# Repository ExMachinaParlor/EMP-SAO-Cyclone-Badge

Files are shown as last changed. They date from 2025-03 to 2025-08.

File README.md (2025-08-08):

# EMP SAO Cyclone Badge
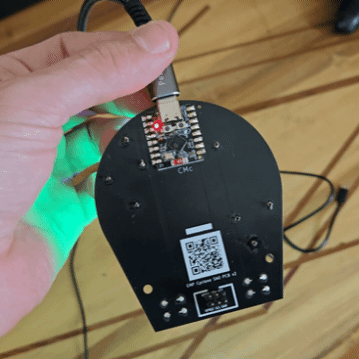
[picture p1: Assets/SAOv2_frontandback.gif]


# Description
SAO with a simple arcade game similar to the classic Cyclone. Made to run on an ESP32-C3 and to interface with [Neopixel rings](https://www.adafruit.com/product/1463#technical-details).

# How to Play
## Attract Mode
A rotating purple LED on the outer ring and a slow blink of green on the inner ring is the default state
The SAO waits for a button press to transition to START_GAME

## Start Game
Resets the chasing light and randomly selects one of the LEDs to act as the target
Displays the jackpot briefly with a blue color. Immediately transitions to PLAY_GAME

## Play Game
A single lit LED moves around the outer ring.
The goal is to press the button when the active LED is over the previously displayed target LED

## Result
If the button is pressed when the active LED is on the target, it’s a win animation of flashing green
Otherwise, a lose animation of flashing red
After the animation the SAO returns to ATTRACT_MODE

# SAO BOM
- 1x [ESP32-C3 Nano](https://www.amazon.com/ESP32-C3-Development-Bluetooth-Running-Frequency/dp/B0DFWG87JS/?th=1)
- 1x [24 LED Neopixel ring](https://www.amazon.com/dp/B0B2D7742J)
- 1x [16 LED Neopixel ring](https://www.amazon.com/dp/B0B2D5QXG5)
- 2x [Push buttons](https://www.amazon.com/dp/B01CGMP9GY)
- 1x [2x3 0.1" Header pin box connector](https://www.amazon.com/gp/product/B00UBWKQLA/)
- 1x [SAO PCB](./PCB/EMP_Cyclone_SAO_v2/Gerber.zip)
- 8x 0.1" Header pins (Included in ESP32-C3 purchase)

# Flashing the Badge
- Use the arduino IDE
- Set board type to "nologo ESP32C3 Supermini"

# Future Work
- Add multiplayer mode
- Test with WLED and home assistant
- Use WiFi/BT to synchonize lights on multiple badges

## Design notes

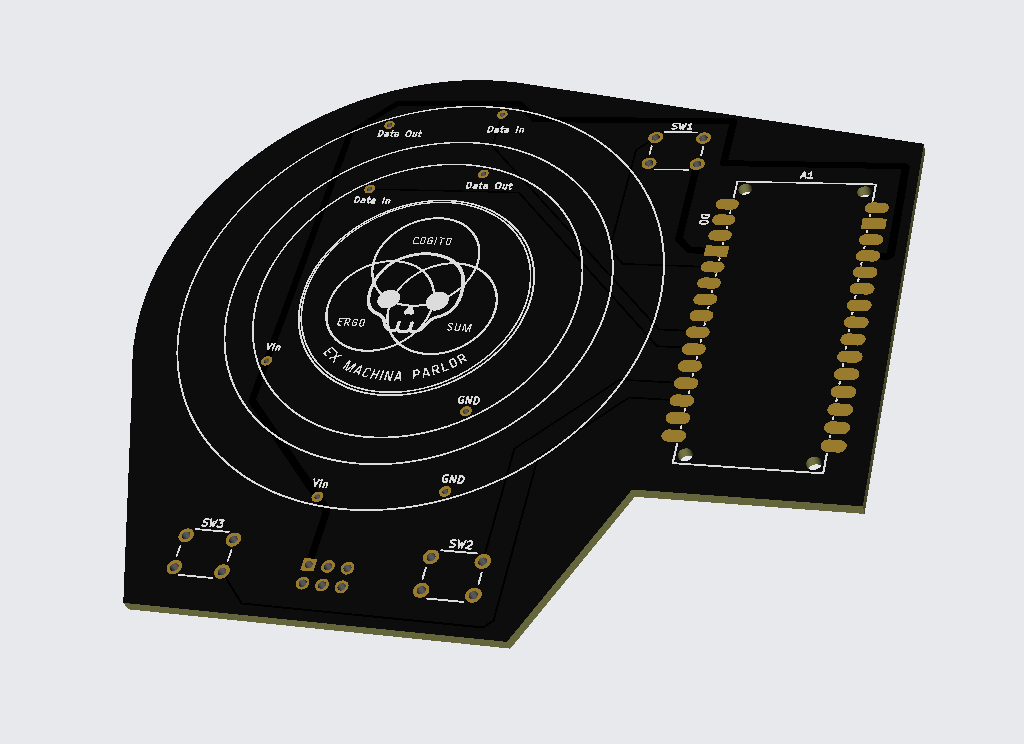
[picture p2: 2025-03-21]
Assets/PCBv1.png

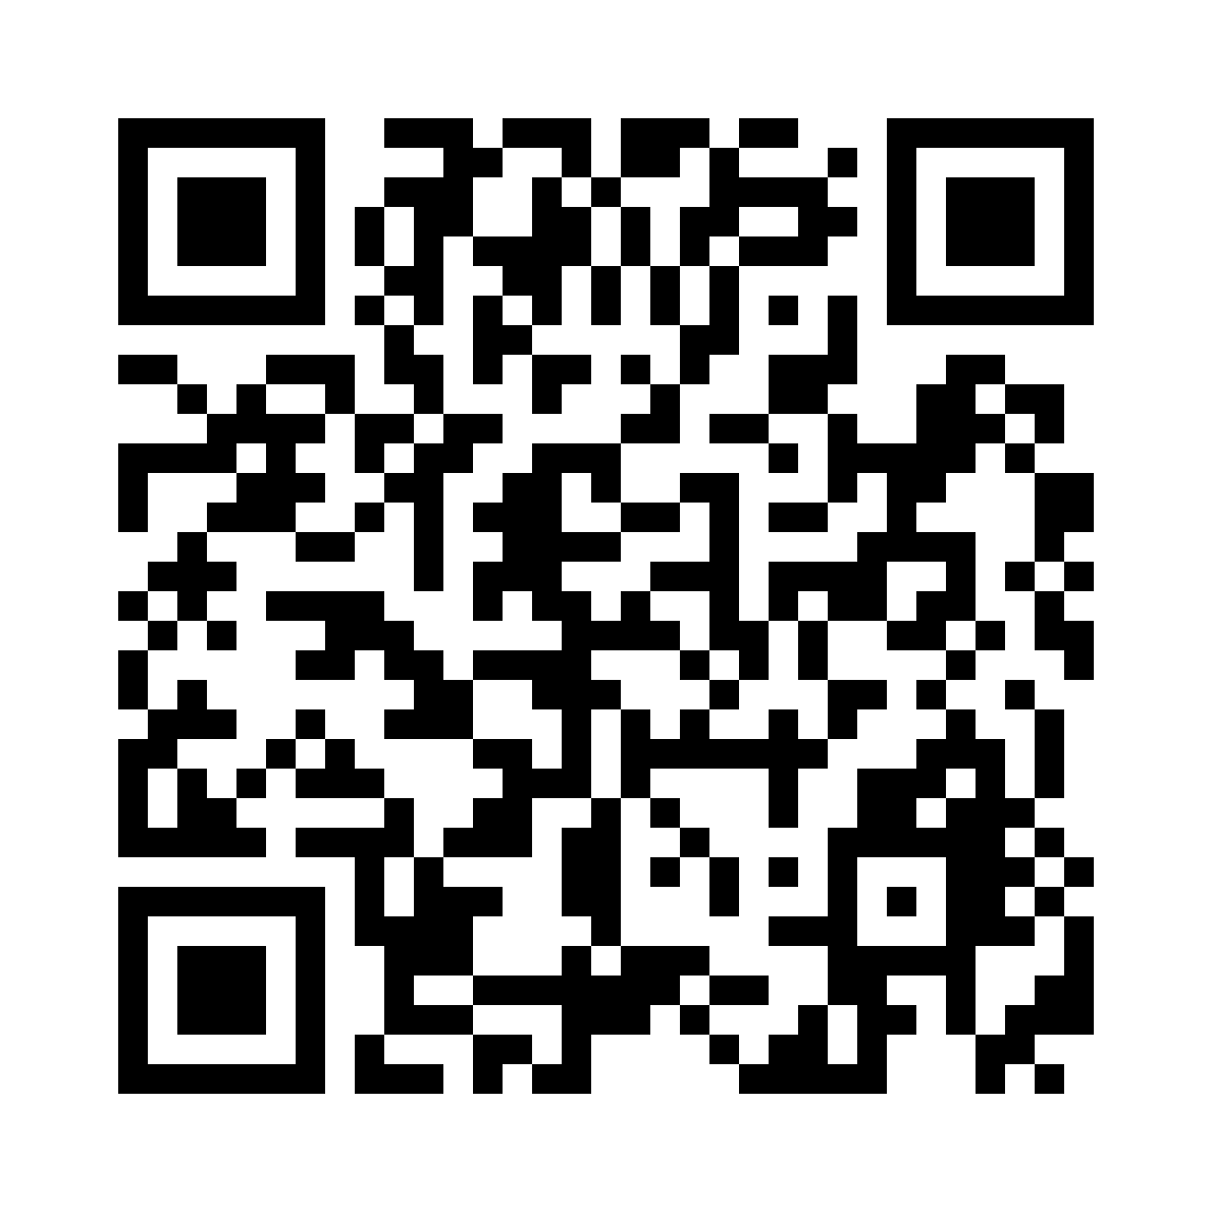
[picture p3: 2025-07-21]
Assets/repoQR.png

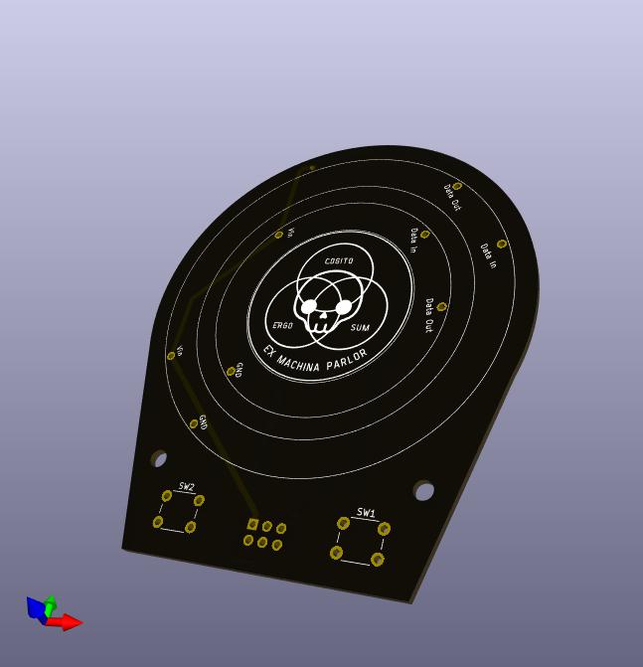
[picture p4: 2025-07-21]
Assets/SAOv2_3Dpcb.jpg

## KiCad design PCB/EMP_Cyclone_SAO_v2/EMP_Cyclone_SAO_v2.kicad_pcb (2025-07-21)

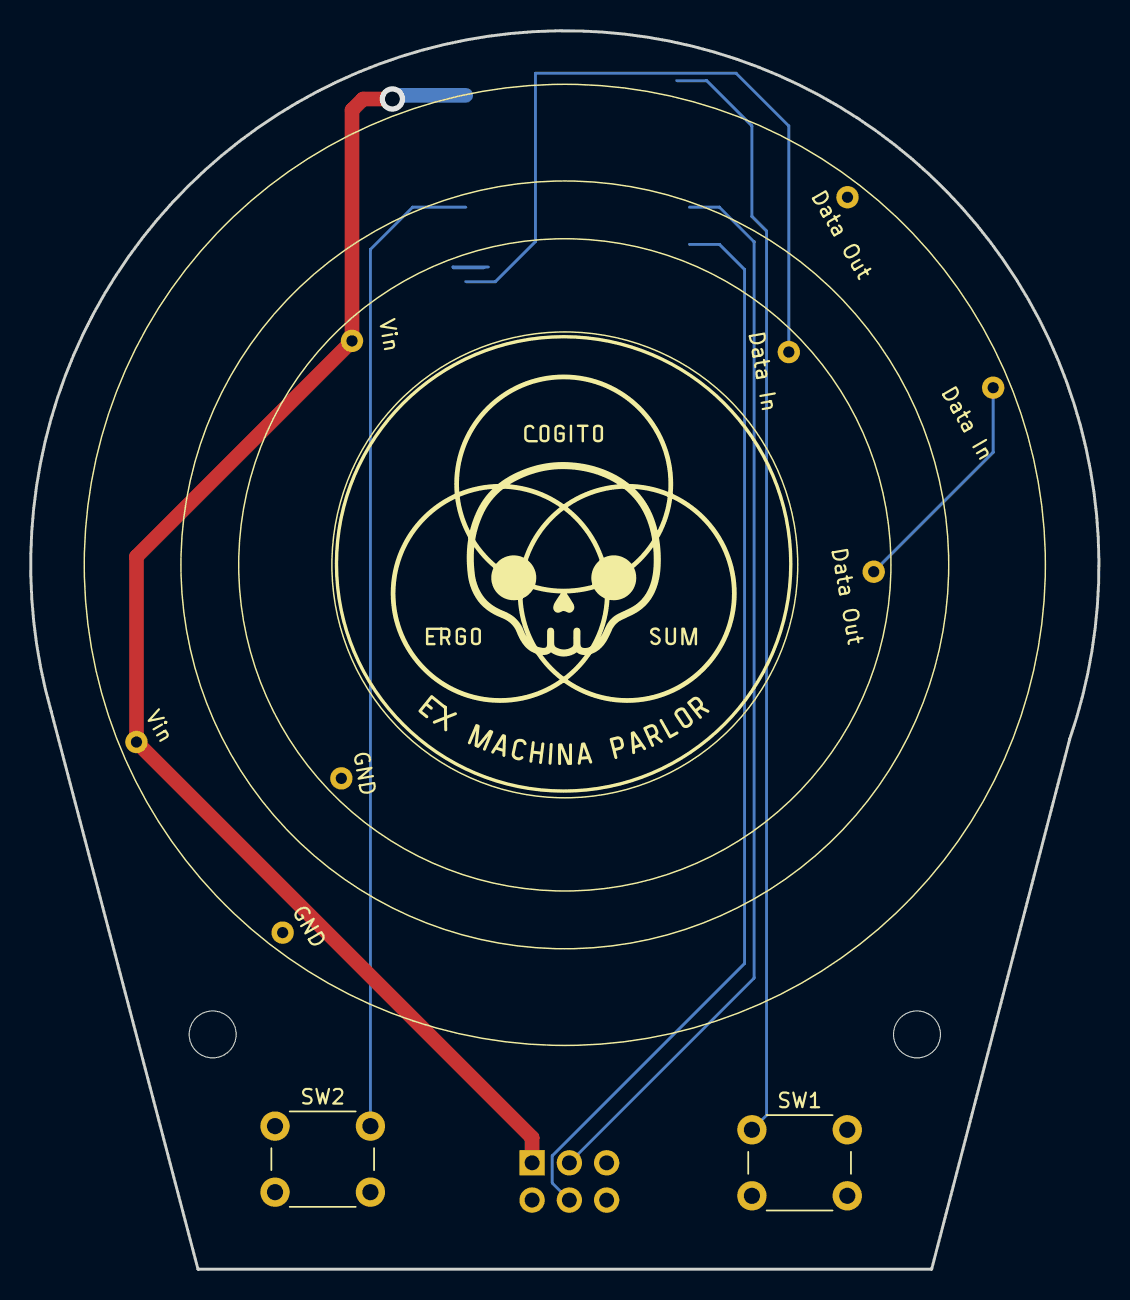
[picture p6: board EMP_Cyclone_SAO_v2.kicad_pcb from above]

Board: 2 copper layers, 72.8 x 84.4 mm, 5 parts (1 on the bottom side), 5 nets.

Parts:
SW1, SW2: SW_Push; SW_PUSH_6mm
U1: Neopixel_Ring_16
U2: Neopixel_Ring_24
U3: ESP32-C3_SUPERMINI; MODULE_ESP32-C3_SUPERMINI

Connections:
+5V: U1.3, U2.3, U3.5V
GND: SW1.2, SW2.2, U1.4, U2.4, U3.G (GND)
unnamed: U1.1, U3.2 (GPIO2)
unnamed: SW2.1, U3.4 (GPIO4)
unnamed: SW1.1, U3.5 (GPIO5)

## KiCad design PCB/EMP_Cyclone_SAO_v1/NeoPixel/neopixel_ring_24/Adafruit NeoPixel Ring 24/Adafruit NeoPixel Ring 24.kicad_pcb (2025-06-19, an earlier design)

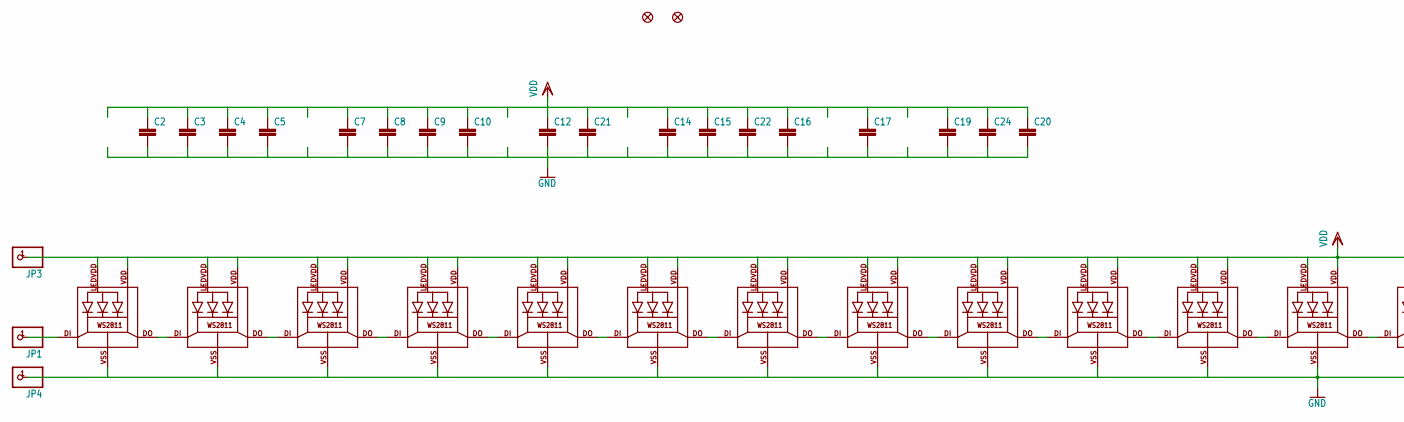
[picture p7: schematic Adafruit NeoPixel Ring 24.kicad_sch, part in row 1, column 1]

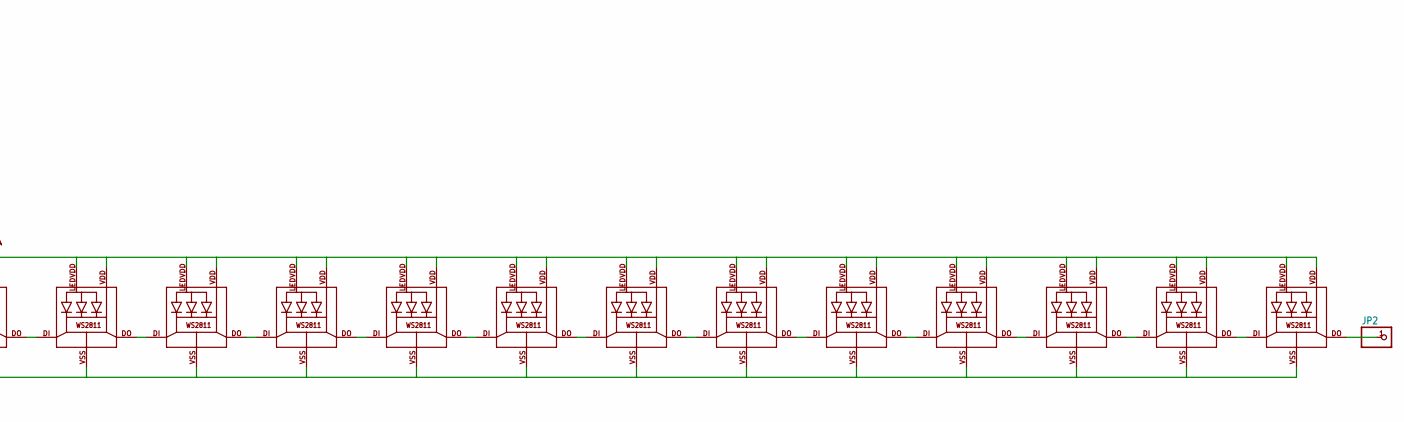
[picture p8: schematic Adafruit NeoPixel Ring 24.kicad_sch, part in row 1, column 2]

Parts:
C2, C3, C4, C5, C7, C8, C9, C10, C12, C14, C15, C16, C17, C19, C20, C21, C22, C24: C-EUC0603; C0603
FID1, FID2: FIDUCIAL""; FIDUCIAL_1MM
JP1, JP2, JP3, JP4: PINHD-1X1CB; 1X01-CLEANBIG
LED1, LED2, LED3, LED4, LED5, LED6, LED7, LED8, LED9, LED10, LED11, LED12, LED13, LED14, LED15, LED16, LED17, LED18, LED19, LED20, LED21, LED22, LED23, LED24: WS28115050

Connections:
GND: C2.2, C3.2, C4.2, C5.2, C7.2, C8.2, C9.2, C10.2, C12.2, C14.2, C15.2, C16.2, C17.2, C19.2, C20.2, C21.2, C22.2, C24.2, JP4.1, LED1.VSS (GND), LED2.VSS (GND), LED3.VSS (GND), LED4.VSS (GND), LED5.VSS (GND), LED6.VSS (GND), LED7.VSS (GND), LED8.VSS (GND), LED9.VSS (GND), LED10.VSS (GND), LED11.VSS (GND), LED12.VSS (GND), LED13.VSS (GND), LED14.VSS (GND), LED15.VSS (GND), LED16.VSS (GND), LED17.VSS (GND), LED18.VSS (GND), LED19.VSS (GND), LED20.VSS (GND), LED21.VSS (GND), LED22.VSS (GND), LED23.VSS (GND), LED24.VSS (GND)
unnamed: LED1.DO, LED2.DI
unnamed: LED2.DO, LED3.DI
unnamed: LED3.DO, LED4.DI
unnamed: LED4.DO, LED5.DI
unnamed: LED5.DO, LED6.DI
unnamed: LED6.DO, LED7.DI
unnamed: LED7.DO, LED8.DI
unnamed: LED8.DO, LED9.DI
unnamed: LED9.DO, LED10.DI
unnamed: LED10.DO, LED11.DI
unnamed: LED11.DO, LED12.DI
unnamed: LED12.DO, LED13.DI
unnamed: LED13.DO, LED14.DI
unnamed: LED14.DO, LED15.DI
unnamed: LED15.DO, LED16.DI
unnamed: LED16.DO, LED17.DI
unnamed: LED17.DO, LED18.DI
unnamed: LED18.DO, LED19.DI
unnamed: LED19.DO, LED20.DI
unnamed: LED20.DO, LED21.DI
unnamed: LED21.DO, LED22.DI
unnamed: LED22.DO, LED23.DI
unnamed: LED23.DO, LED24.DI
unnamed: JP2.1, LED24.DO
unnamed: JP1.1, LED1.DI
VDD: C2.1, C3.1, C4.1, C5.1, C7.1, C8.1, C9.1, C10.1, C12.1, C14.1, C15.1, C16.1, C17.1, C19.1, C20.1, C21.1, C22.1, C24.1, JP3.1, LED1.LEDVDD, LED1.VDD, LED2.LEDVDD, LED2.VDD, LED3.LEDVDD, LED3.VDD, LED4.LEDVDD, LED4.VDD, LED5.LEDVDD, LED5.VDD, LED6.LEDVDD, LED6.VDD, LED7.LEDVDD, LED7.VDD, LED8.LEDVDD, LED8.VDD, LED9.LEDVDD, LED9.VDD, LED10.LEDVDD, LED10.VDD, LED11.LEDVDD, LED11.VDD, LED12.LEDVDD, LED12.VDD, LED13.LEDVDD, LED13.VDD, LED14.LEDVDD, LED14.VDD, LED15.LEDVDD, LED15.VDD, LED16.LEDVDD, LED16.VDD, LED17.LEDVDD, LED17.VDD, LED18.LEDVDD, LED18.VDD, LED19.LEDVDD, LED19.VDD, LED20.LEDVDD, LED20.VDD, LED21.LEDVDD, LED21.VDD, LED22.LEDVDD, LED22.VDD, LED23.LEDVDD, LED23.VDD, LED24.LEDVDD, LED24.VDD

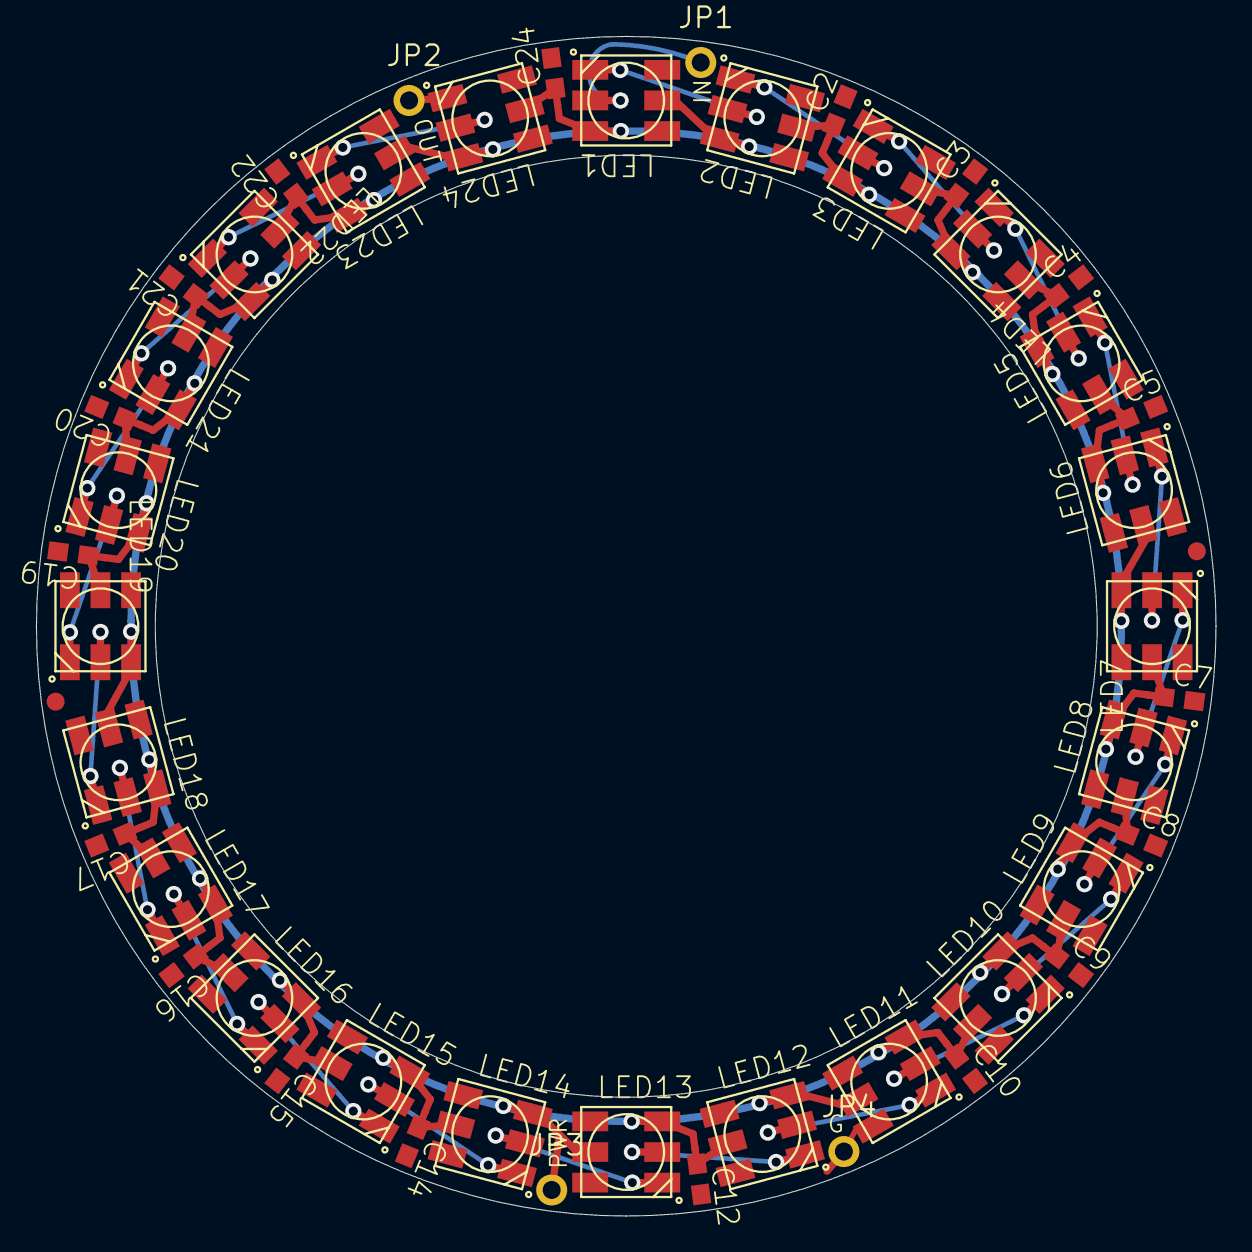
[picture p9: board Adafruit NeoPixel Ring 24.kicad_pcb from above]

Board: 2 copper layers, 65.5 x 65.5 mm, 49 parts (1 on the bottom side), 27 nets.

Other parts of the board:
U$1: ADAFRUIT_5MM

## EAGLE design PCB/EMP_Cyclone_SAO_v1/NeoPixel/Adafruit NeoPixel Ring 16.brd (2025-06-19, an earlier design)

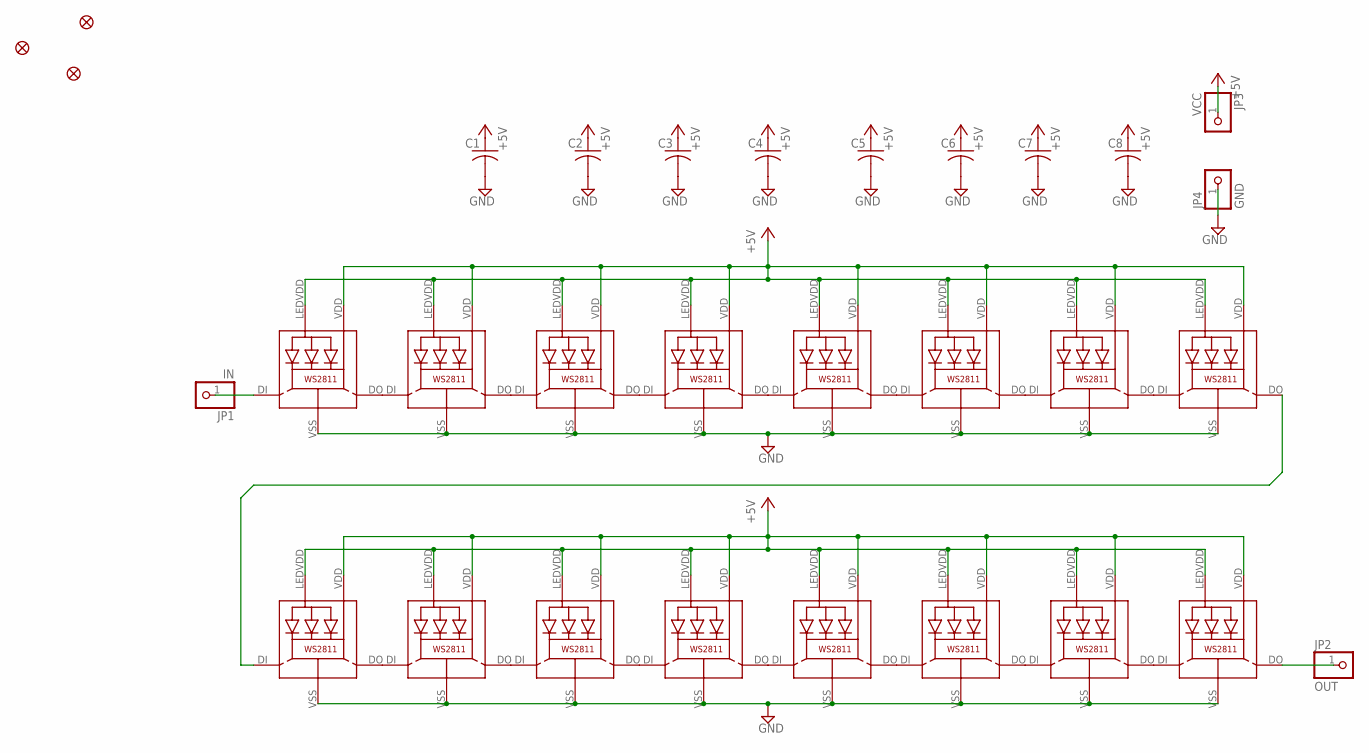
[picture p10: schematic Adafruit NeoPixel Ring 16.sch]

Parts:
C1: C-USC0603; C0603
C2, C3, C4, C5, C6, C7, C8: C-USC0603K; C0603K
FID1, FID2, FID3: FIDUCIAL""; FIDUCIAL_1MM
JP1: IN; 1X01-CLEANBIG
JP2: OUT; 1X01-CLEANBIG
JP3: VCC; 1X01-CLEANBIG
JP4: GND; 1X01-CLEANBIG
LED1, LED2, LED3, LED4, LED5, LED6, LED7, LED8, LED9, LED10, LED11, LED12, LED13, LED14, LED15, LED16: WS28115050

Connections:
+5V: C1.1, C2.1, C3.1, C4.1, C5.1, C6.1, C7.1, C8.1, JP3.1, LED1.LEDVDD, LED1.VDD, LED2.LEDVDD, LED2.VDD, LED3.LEDVDD, LED3.VDD, LED4.LEDVDD, LED4.VDD, LED5.LEDVDD, LED5.VDD, LED6.LEDVDD, LED6.VDD, LED7.LEDVDD, LED7.VDD, LED8.LEDVDD, LED8.VDD, LED9.LEDVDD, LED9.VDD, LED10.LEDVDD, LED10.VDD, LED11.LEDVDD, LED11.VDD, LED12.LEDVDD, LED12.VDD, LED13.LEDVDD, LED13.VDD, LED14.LEDVDD, LED14.VDD, LED15.LEDVDD, LED15.VDD, LED16.LEDVDD, LED16.VDD
GND: C1.2, C2.2, C3.2, C4.2, C5.2, C6.2, C7.2, C8.2, JP4.1, LED1.VSS (GND), LED2.VSS (GND), LED3.VSS (GND), LED4.VSS (GND), LED5.VSS (GND), LED6.VSS (GND), LED7.VSS (GND), LED8.VSS (GND), LED9.VSS (GND), LED10.VSS (GND), LED11.VSS (GND), LED12.VSS (GND), LED13.VSS (GND), LED14.VSS (GND), LED15.VSS (GND), LED16.VSS (GND)
IN: JP1.1, LED1.DI
unnamed: LED1.DO, LED2.DI
unnamed: LED2.DO, LED3.DI
unnamed: LED3.DO, LED4.DI
unnamed: LED4.DO, LED5.DI
unnamed: LED5.DO, LED6.DI
unnamed: LED6.DO, LED7.DI
unnamed: LED7.DO, LED8.DI
unnamed: LED9.DO, LED10.DI
unnamed: LED10.DO, LED11.DI
unnamed: LED11.DO, LED12.DI
unnamed: LED12.DO, LED13.DI
unnamed: LED13.DO, LED14.DI
unnamed: LED14.DO, LED15.DI
unnamed: LED15.DO, LED16.DI
unnamed: LED8.DO, LED9.DI
OUT: JP2.1, LED16.DO

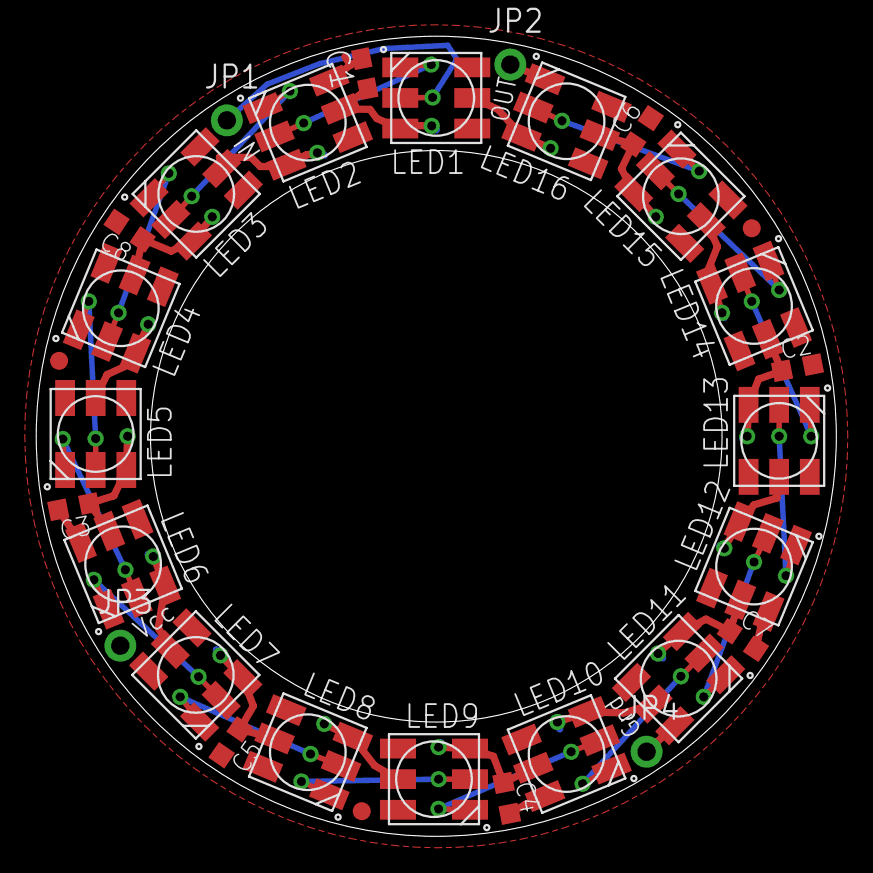
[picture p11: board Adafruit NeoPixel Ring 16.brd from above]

Board: 2 copper layers, 44.5 x 44.5 mm, 32 parts (1 on the bottom side), 19 nets.

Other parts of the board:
U$2: ADAFRUIT_5MM

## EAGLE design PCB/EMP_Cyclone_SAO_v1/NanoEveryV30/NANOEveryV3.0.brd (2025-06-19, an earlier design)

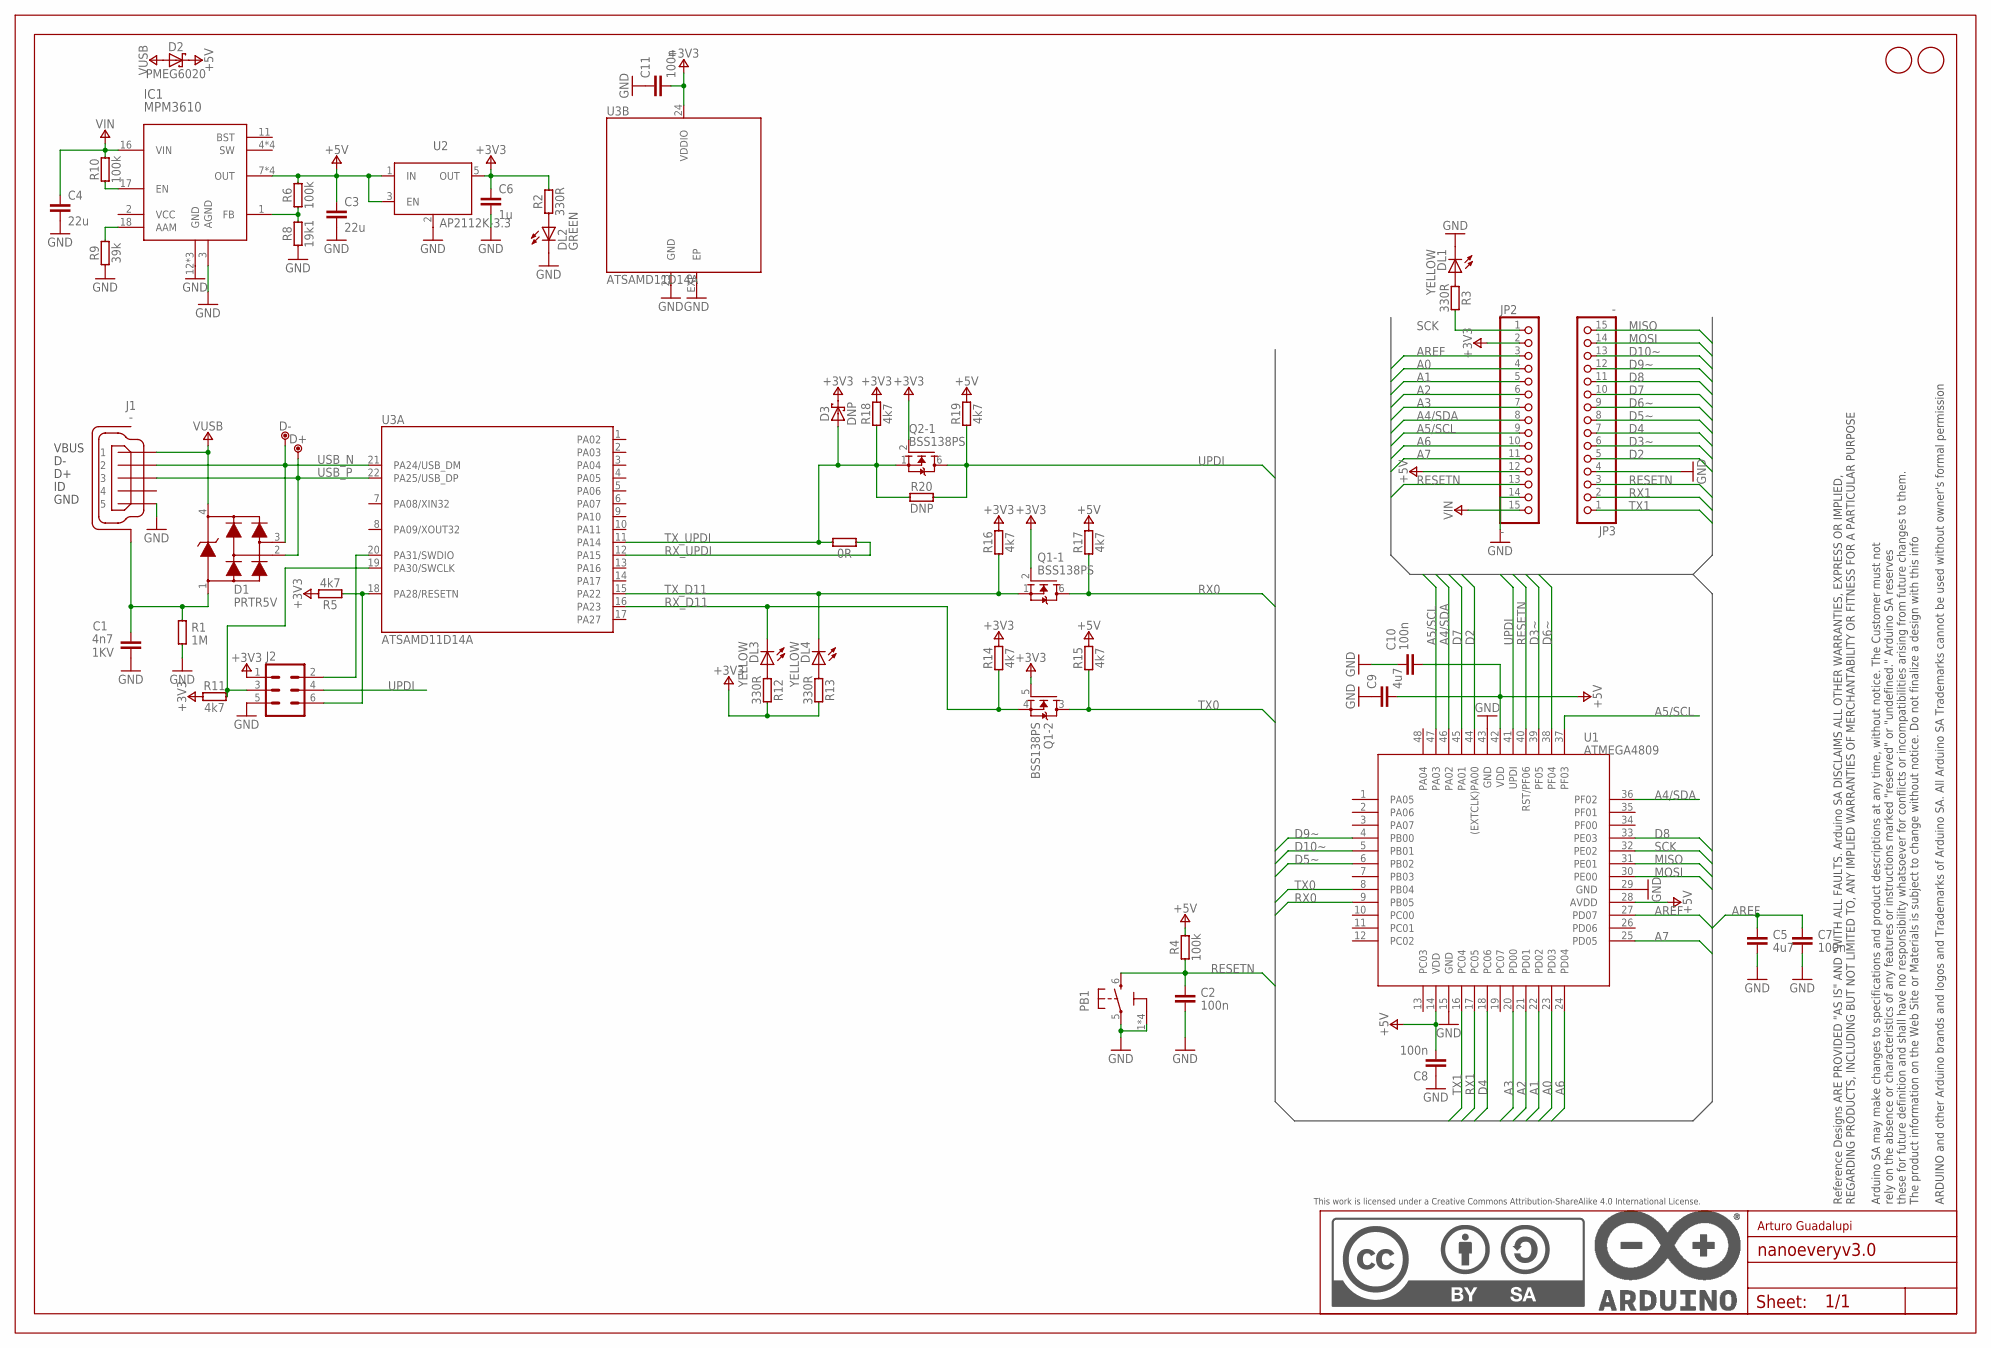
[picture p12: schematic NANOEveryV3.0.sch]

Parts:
C1: 4n7; 0805-R2013X50N; VOLTAGE 1KV
C2, C7, C8, C10, C11: 100n; 0402-1005X55N
C3, C4: 22u; 0805-R2013X50N
C5, C9: 4u7; 0402-1005X55N
C6: 1u; 0402-1005X55N
D1: PRTR5V; SOT190P230X110-4N
D2: PMEG6020; SODFL3517X110N
D3: DNP; SODFL3517X110N
D+: DNP; TP-1.00MM
D-: DNP; TP-1.00MM
DL1, DL3, DL4: YELLOW; LEDC1608X80N-AK
DL2: GREEN; LEDC1608X80N-AK
FD1, FD2: DNP; FD-1-1.5
FRAME1: DNP; FRAME
IC1: MPM3610
J1: -; ZX62-AB-5PA
J2: DNP; 2X03-TP
JP2, JP3: -; 1X15-CASTELL
PB1: PTS820; C&K_PTS820_NO_HOLES
Q1, Q2: BSS138PS; SOT363
R1: 1M; 0402-1005X55N
R2, R3, R12, R13: 330R; 0402-1005X55N
R4, R6, R10: 100k; 0402-1005X55N
R5, R11, R14, R15, R16, R17, R18, R19: 4k7; 0402-1005X55N
R7: 0R; 0402-1005X55N
R8: 19k1; 0402-1005X55N
R9: 39k; 0402-1005X55N
R20: DNP; 0402-1005X55N
U1: ATMEGA4809; TQFP48
U2: AP2112K-3.3; SOT25
U3: ATSAMD11D14A; HVQFN24

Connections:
+3V3: C6.1, C11.2, D3.C, J2.1, JP2.2, Q1.2 (G), Q1.5 (G), Q2.2 (G), R2.2, R5.2, R11.1, R12.2, R13.2, R14.2, R16.2, R18.2, U2.5 (OUT), U3.24 (VDDIO)
+5V: C3.1, C8.2, C9.2, C10.2, D2.C, IC1.7 (OUT), IC1.8 (OUT), IC1.9 (OUT), IC1.20 (OUT), JP2.12, R4.2, R6.2, R15.2, R17.2, R19.2, U1.14 (VDD), U1.28 (AVDD), U1.42 (VDD), U2.1 (IN), U2.3 (EN)
A0: JP2.4, U1.23 (PD03)
A1: JP2.5, U1.22 (PD02)
A2: JP2.6, U1.21 (PD01)
A3: JP2.7, U1.20 (PD00)
A4/SDA: JP2.8, U1.36 (PF02), U1.46 (PA02)
A5/SCL: JP2.9, U1.37 (PF03), U1.47 (PA03)
A6: JP2.10, U1.24 (PD04)
A7: JP2.11, U1.25 (PD05)
AREF: C5.1, C7.1, JP2.3, U1.27 (PD07)
D2: JP3.5, U1.44 ((EXTCLK)PA00)
D3~: JP3.6, U1.39 (PF05)
D4: JP3.7, U1.18 (PC06)
D5~: JP3.8, U1.6 (PB02)
D6~: JP3.9, U1.38 (PF04)
D7: JP3.10, U1.45 (PA01)
D8: JP3.11, U1.33 (PE03)
D9~: JP3.12, U1.4 (PB00)
D10~: JP3.13, U1.5 (PB01)
D11_RESET: J2.6, R5.1, U3.18 (PA28/RESETN)
D11_SWCLK: J2.3, R11.2, U3.19 (PA30/SWCLK)
D11_SWDIO: J2.2, U3.20 (PA31/SWDIO)
GND: C1.2, C2.2, C3.2, C4.2, C5.2, C6.2, C7.2, C8.1, C9.1, C10.1, C11.1, DL1.C, DL2.C, IC1.3 (AGND), IC1.12 (GND), IC1.13 (GND), IC1.14 (GND), J1.5, J2.5, JP2.14, JP3.4, PB1.1 (3), PB1.2 (3), PB1.3, PB1.4 (3), PB1.5 (1), R1.1, R8.1, R9.1, U1.15 (GND), U1.29 (GND), U1.43 (GND), U2.2 (GND/ADJ), U3.23 (GND), U3.EXP (EP)
MISO: JP3.15, U1.31 (PE01)
MOSI: JP3.14, U1.30 (PE00)
unnamed: C1.1, D1.1, J1.6 (SH), J1.7 (SH), J1.8 (SH), J1.9 (SH), J1.10 (SH), J1.11 (SH), R1.2
unnamed: DL2.A, R2.1
unnamed: DL1.A, R3.1
unnamed: IC1.1 (FB), R6.1, R8.2
unnamed: IC1.18 (AAM), R9.2
unnamed: IC1.17 (EN), R10.1
unnamed: DL3.A, R12.1
unnamed: DL4.A, R13.1
RESETN: C2.1, JP2.13, JP3.3, PB1.6 (2), R4.1, U1.40 (RST/PF06)
RX0: Q1.6 (D), R17.1, U1.9 (PB05)
RX1: JP3.2, U1.17 (PC05)
RX_D11: DL3.C, Q1.4 (S), R14.1, U3.16 (PA23)
RX_UPDI: R7.2, U3.12 (PA15)
SCK: JP2.1, R3.2, U1.32 (PE02)
TX0: Q1.3 (D), R15.1, U1.8 (PB04)
TX1: JP3.1, U1.16 (PC04)
TX_D11: DL4.C, Q1.1 (S), R16.1, U3.15 (PA22)
TX_UPDI: D3.A, Q2.1 (S), R7.1, R18.1, R20.1, U3.11 (PA14)
UPDI: J2.4, Q2.6 (D), R19.1, R20.2, U1.41 (UPDI)
USB_N: D1.3, D-.X, J1.2, U3.21 (PA24/USB_DM)
USB_P: D1.2, D+.X, J1.3, U3.22 (PA25/USB_DP)
VIN: C4.1, IC1.16 (VIN), JP2.15, R10.2
VUSB: D1.4, D2.A, J1.1

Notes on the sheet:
Arturo Guadalupi

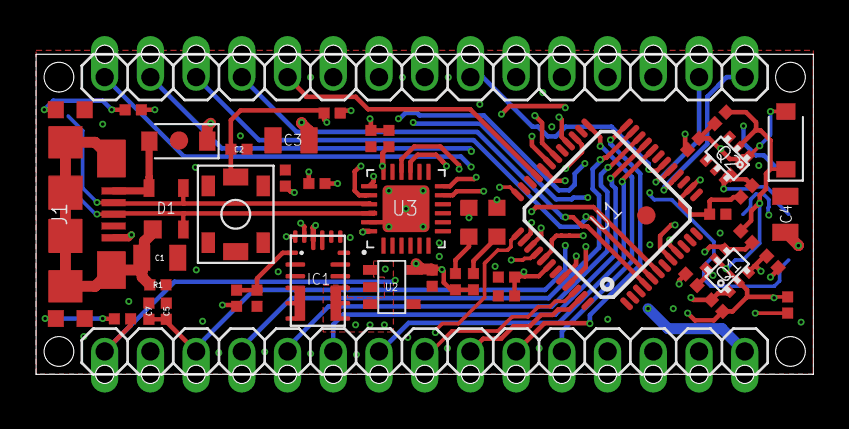
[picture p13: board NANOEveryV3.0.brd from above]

Board: 4 copper layers, 43.2 x 17.8 mm, 54 parts (0 on the bottom side), 49 nets.

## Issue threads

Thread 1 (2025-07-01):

SAO v2 PCB

ConorMcCaffrey, 2025-07-01:
Make an updated verison using a cheaper more available chip. Looking at the ESC-c3 supermini board on aliexpress.

# To Do from V1
- [x] Need to make vias bigger for through hole LED posts
- [x] need to add additional power pins for led ring
- [x] Ground does not seem to be connected for the LED ring
- [x] PCB serial number label was written on wrong side
   - [x] See if that is my mistake or theirs
- [x] Check new ESP32 chip will run on the voltage from the SAO board
- [x] Add mounting/standoff holes
- [x] Test power from badge

ConorMcCaffrey, 2025-07-01:
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

ConorMcCaffrey, 2025-07-01:
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

New esp work with SAO power

ConorMcCaffrey, 2025-07-13:
- Tested new v2 boards
- everything seems to work well
- a few small fixes
- [ ] Remove label above left button
- [ ] Swap SW1 and SW2 (can keep same pins mostly want to swap the labels so sw1 is on the left)
- [ ] update QR code to point to new repo
- [ ] Move latest changes to new repo

ConorMcCaffrey, 2025-07-21:
New version ordered. Left the button labels as it was a hassle to change them. Used a note to tell jlbpcb to make the board with the serial number where indicated on the rear silkscreen (fingers crossed)

Closed 2025-07-21.

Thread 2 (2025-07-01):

Update PCB for lower cost components

ConorMcCaffrey, 2025-07-01:
- [ ] Find lower cost arduino
  - Previous discussion about arduino boards
    - #1
- [ ] Look at lower cost LED rings or placing our own neopixels

ConorMcCaffrey, 2025-07-01:
**Looking at this as an alternative Arduino:**

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

[NANO V3.0 / Nano SuperMini Type-C](https://www.aliexpress.us/item/3256806299801446.html)
- Super cheap
- small
- usb-C
- May or may not always be available
- may not have good documentation

ConorMcCaffrey, 2025-07-21:
Added new SAO BOM to main readme. Still a work in progress. Stuff keeps going out of stock. The links have been changing to other products. Shipping is all over the map. This is the most current version.

# SAO BOM
- [ESP32-C3 Nano](https://www.amazon.com/ESP32-C3-Development-Bluetooth-Running-Frequency/dp/B0DFWG87JS/?th=1)
- 1x [24 LED Neopixel ring](https://www.amazon.com/dp/B0B2D7742J)
- 1x [16 LED Neopixel ring](https://www.amazon.com/dp/B0B2D5QXG5)
- 2x [Push button](https://www.amazon.com/YOUFEN-Button-Switch-Momentary-Tactile/dp/B0DPJVH8PC)
- 1x PCB (from assets here)
- 8x 0.1" Header pins (Included in ESP32-C3 purchase)
- 1x [2x3 0.1" Header pin box connector](https://www.amazon.com/gp/product/B00UBWKQLA/)

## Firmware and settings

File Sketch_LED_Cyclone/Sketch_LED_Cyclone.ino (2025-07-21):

#include <Adafruit_NeoPixel.h>

/***********************************************************
   Pin & LED Configuration
 ***********************************************************/
#define DATA_PIN            2   // Data pin for both NeoPixel rings
#define SMALL_RING_NUM      16  // Number of LEDs in the small (inner) ring
#define LARGE_RING_NUM      24  // Number of LEDs in the large (outer) ring
#define TOTAL_PIXELS        (SMALL_RING_NUM + LARGE_RING_NUM)
#define BUTTON_PIN          4   // Push button input pin

/***********************************************************
   NeoPixel Object
 ***********************************************************/
Adafruit_NeoPixel strip(TOTAL_PIXELS, DATA_PIN, NEO_GRB + NEO_KHZ800);

// Offsets into the single strip
const uint16_t smallOffset = 0;
const uint16_t largeOffset = SMALL_RING_NUM;

/***********************************************************
   Game State Definitions
 ***********************************************************/
enum GameState {
  ATTRACT_MODE,
  START_GAME,
  PLAY_GAME,
  RESULT
};
GameState currentState = ATTRACT_MODE;

/***********************************************************
   Game Variables
 ***********************************************************/
unsigned long chaseInterval = 80;     // Delay (ms) between chase steps
unsigned long lastChaseUpdate = 0;    // Time of last chase step
int chaseIndex = 0;                   // Current chase position (0..LARGE_RING_NUM-1)
int jackpotIndex = 0;                 // Winning position on large ring
bool winner = false;                  // Outcome flag

// Button debounce
bool lastButtonState = HIGH;
bool buttonPressed = false;

/***********************************************************
   Setup
 ***********************************************************/
void setup() {
  Serial.begin(9600);
  strip.begin();
  strip.show(); // Initialize all off
  pinMode(BUTTON_PIN, INPUT_PULLUP);
  Serial.println("Cyclone-Style Game Starting...");
}

/***********************************************************
   Main Loop
 ***********************************************************/
void loop() {
  readButton();
  switch (currentState) {
    case ATTRACT_MODE: attractMode(); break;
    case START_GAME:   startGame();   break;
    case PLAY_GAME:    playGame();    break;
    case RESULT:       showResult();  break;
  }
}

/***********************************************************
   Attract Mode
 ***********************************************************/
void attractMode() {
  static unsigned long lastUpdate = 0;
  unsigned long t = millis();
  if (t - lastUpdate > 100) {
    lastUpdate = t;
    static int attractIdx = 0;
    strip.clear();

    // Rotate one purple pixel on outer (large) ring
    strip.setPixelColor(largeOffset + attractIdx, strip.Color(50, 0, 50));

    // Blink inner (small) ring dim green every other step
    if ((attractIdx % 4) < 2) {
      for (uint16_t i = 0; i < SMALL_RING_NUM; i++) {
        strip.setPixelColor(smallOffset + i, strip.Color(0, 30, 0));
      }
    }

    strip.show();
    attractIdx = (attractIdx + 1) % LARGE_RING_NUM;
  }
  if (buttonPressed) { buttonPressed = false; currentState = START_GAME; }
}

/***********************************************************
   Start Game
 ***********************************************************/
void startGame() {
  jackpotIndex = random(0, LARGE_RING_NUM);
  Serial.print("New Game - Jackpot Index (outer ring): ");
  Serial.println(jackpotIndex);
  chaseIndex = 0;
  lastChaseUpdate = millis();
  winner = false;

  // Clear all
  strip.clear();
  strip.show();

  // Show jackpot on outer ring (blue) for 2s
  strip.setPixelColor(largeOffset + jackpotIndex, strip.Color(0, 0, 255));
  strip.show();
  delay(2000);

  strip.clear();
  strip.show();
  currentState = PLAY_GAME;
}

/***********************************************************
   Play Game
 ***********************************************************/
void playGame() {
  unsigned long t = millis();
  if (t - lastChaseUpdate >= chaseInterval) {
    lastChaseUpdate = t;
    chaseIndex = (chaseIndex + 1) % LARGE_RING_NUM;
    strip.clear();
    strip.setPixelColor(largeOffset + chaseIndex, strip.Color(255, 0, 0));
    strip.show();
  }
  if (buttonPressed) {
    buttonPressed = false;
    if (chaseIndex == jackpotIndex) {
      winner = true;
      Serial.println("Jackpot HIT!");
    } else {
      winner = false;
      Serial.print("Jackpot MISS! Stopped at ");
      Serial.print(chaseIndex);
      Serial.print(", jackpot is ");
      Serial.println(jackpotIndex);
    }
    currentState = RESULT;
  }
}

/***********************************************************
   Result Animation
 ***********************************************************/
void showResult() {
  if (winner) {
    for (int i = 0; i < 3; i++) {
      // Flash both rings green
      for (uint16_t p = 0; p < TOTAL_PIXELS; p++) strip.setPixelColor(p, strip.Color(0, 255, 0));
      strip.show(); delay(300);
      strip.clear(); strip.show(); delay(300);
    }
  } else {
    for (int i = 0; i < 3; i++) {
      strip.clear();
      // Show jackpot (yellow) and stopped (red) on outer ring
      strip.setPixelColor(largeOffset + jackpotIndex, strip.Color(255, 255, 0));
      strip.setPixelColor(largeOffset + chaseIndex,   strip.Color(255, 0, 0));
      // Flash inner ring red
      for (uint16_t p = 0; p < SMALL_RING_NUM; p++) strip.setPixelColor(smallOffset + p, strip.Color(255, 0, 0));
      strip.show(); delay(300);
      strip.clear(); strip.show(); delay(300);
    }
  }
  currentState = ATTRACT_MODE;
}

/***********************************************************
   readButton(): Debounce & detect press
 ***********************************************************/
void readButton() {
  bool currState = digitalRead(BUTTON_PIN);
  if (lastButtonState == HIGH && currState == LOW) {
    Serial.println("Button pressed!");
    buttonPressed = true;
  }
  lastButtonState = currState;
}

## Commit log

2025-03-19 Initial build for Arduino Pro Mini
2025-03-19 Change number of lights on ring 1 and move button to pin 3
2025-03-19 Updated game to clearly show the target (jackpot) led before the start of each game
2025-03-20 Adding MVP EMP SAO PCB
    Minimum viable product defcon badge addon printed circuit board
    [EMP_Cyclone_SAO_v1.kicad_pcb, EMP_Cyclone_SAO_v1.kicad_sch]
2025-03-20 Add PNG of PCB
2025-03-20 Added teaser for SAO PCB in readme
2025-03-20 Upload missing kicad files
    [EMP_Cyclone_SAO_v1-B_Cu.gbl, EMP_Cyclone_SAO_v1-B_Mask.gbs, EMP_Cyclone_SAO_v1-B_Paste.gbp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]
2025-03-21 v1. Updated silk screen on pcb. minor changes to traces. Updated gerber files.
    [EMP_Cyclone_SAO_v1-B_Cu.gbl, EMP_Cyclone_SAO_v1-B_Mask.gbs, EMP_Cyclone_SAO_v1-B_Paste.gbp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]
2025-03-21 add new pcb image
2025-03-21 Update README with new PCB image and new gif location
2025-03-29 Tested working on v1 PCB. Updated arduino sketch for pins used on v1 PCB. Minor updates to PCB silkscreen.
    [EMP_Cyclone_SAO_v1.kicad_pcb]
2025-04-20 Updated Gerber Files for the v1 PCB repo. The last commit had the correct kicad files but not updated gerber files.
    [EMP_Cyclone_SAO_v1-B_Cu.gbl, EMP_Cyclone_SAO_v1-B_Mask.gbs, EMP_Cyclone_SAO_v1-B_Paste.gbp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]
2025-04-20 Added extraneous files to repo. Can probably trim some but better to have them uploaded and clean later.
    [Neopixel_hole_locations.ods]
2025-06-19 updated to use ESP32-C3 supermini
    [Adafruit NeoPixel Ring 16.brd, Adafruit NeoPixel Ring 16.kicad_pcb, Adafruit NeoPixel Ring 16.sch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]
2025-06-19 v1.1 in progress with ESP32-C3 moved to back
    [EMP_Cyclone_SAO_v1.kicad_pcb]
2025-06-28 Update files in prep for moving repo
    [EMP_Cyclone_SAO_v1.kicad_sch]
2025-07-13 mode to ESP32-C3 sumper mini (use nologo in arduino flasher). Upload arduino code to test on a single leg ring
    [EMP_Cyclone_SAO_v1-B_Cu.gbl, EMP_Cyclone_SAO_v1-B_Mask.gbs, EMP_Cyclone_SAO_v1-B_Paste.gbp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]
2025-07-21 Updated readme. Cleaned up instructions on how to play. Added new BOM for SAOv2.
2025-07-21 fixed readme BOM link formatting
2025-07-21 EMP SAO v2.1. Gerber files updated and ordered.
    [EMP_Cyclone_SAO_v1-B_Cu.gbl, EMP_Cyclone_SAO_v1-B_Mask.gbs, EMP_Cyclone_SAO_v1-B_Paste.gbp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]
2025-07-21 Re-organized and cleaned up kicad files
    [EMP_Cyclone_SAO_v2-B_Cu.gbl, EMP_Cyclone_SAO_v2-B_Mask.gbs, EMP_Cyclone_SAO_v2-B_Paste.gbp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]
2025-07-21 Fix BOM links and quantities
2025-07-28 Fix push button link on readme
2025-07-29 Second button now controls brightness with four levels. Badge starts on level 2 brightness
2025-08-08 Add brightness control on second button

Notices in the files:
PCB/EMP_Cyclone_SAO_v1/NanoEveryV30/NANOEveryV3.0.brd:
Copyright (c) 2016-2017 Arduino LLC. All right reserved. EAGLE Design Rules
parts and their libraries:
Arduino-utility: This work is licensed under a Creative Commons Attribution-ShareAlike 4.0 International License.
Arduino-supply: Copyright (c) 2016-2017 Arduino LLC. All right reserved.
